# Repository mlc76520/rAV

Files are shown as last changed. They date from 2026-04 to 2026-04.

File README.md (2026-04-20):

# Raspberry Audio Visualizer

A real-time stereo audio visualizer for Raspberry Pi that drives **two SSD1309 128×64 OLED displays** over SPI. Written in a single C++ file with a hardware abstraction layer that lets the same source build on both the **Raspberry Pi 5** (via `lgpio`) and the **Raspberry Pi 3B** (via `bcm2835`).

The project combines live FFT analysis of the system audio output, a full MPD client, Bluetooth (A2DP) metadata monitoring, and a small physical control surface (rotary encoder + four buttons) into a standalone "hi-fi display" appliance.
---
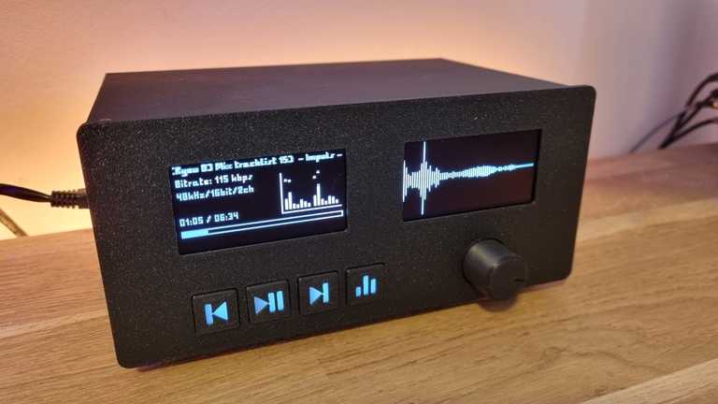
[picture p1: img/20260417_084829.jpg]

---

## Features

- **Six visualization modes**, switchable with a button or auto-cycled after 30 s of inactivity
- **Two independent OLEDs** — left and right channels rendered separately
- **Three-resolution FFT** (8192 / 2048 / 512 points) for accurate bass, mid, and treble bins
- **64-band and 7-band spectrum analyzers** with peak-hold, smoothing, and gravity decay
- **MPD integration** — now-playing info, play/pause, next/previous, volume, and a built-in album/track browser
- **Bluetooth A2DP monitoring** via BlueZ D-Bus — track metadata and auto-pause MPD on BT connect
- **FreeType text rendering** with small / regular / large sizes and UTF-8 support
- **Sleep mode** — after 10 s of silence, both displays fade out with a CRT-style shutdown animation; they wake when audio returns
- **Unified build** — one source file, two backends, selected at compile time with `-DUSE_BCM2835`

---

## Visualization Modes

| Mode | Description |
|---|---|
| **VU Meter** | Analog-style needle with logarithmic dB scale (−20 to +3 dB) |
| **Spectrum** | 7-band filled bars with peak markers and frequency labels (63 Hz → 16 kHz) |
| **Empty Spectrum** | Same 7 bands, outline-only style |
| **Waveform** | Time-domain oscilloscope trace |
| **Track Info** | Scrolling title, bitrate/format, elapsed/total time, progress bar, plus a 64-band mini-spectrum |
| **Playlist Editor** | Browse albums → tracks; play now or add to queue *(UI labels in French)* |

A short volume overlay is drawn over the current visualization whenever the rotary knob is turned.

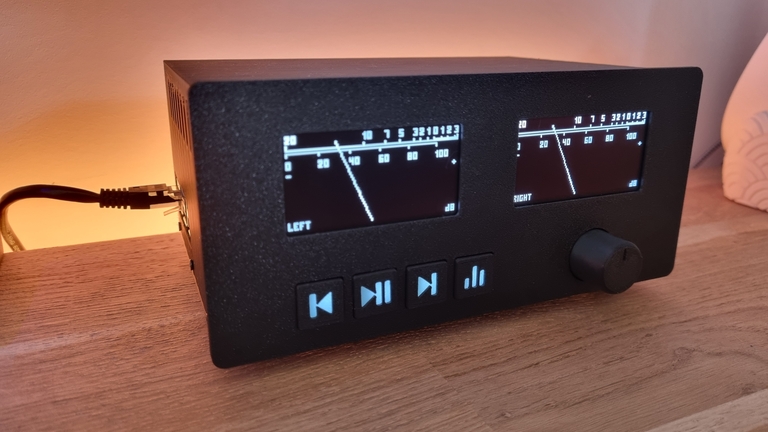
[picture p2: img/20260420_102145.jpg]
VUmeter

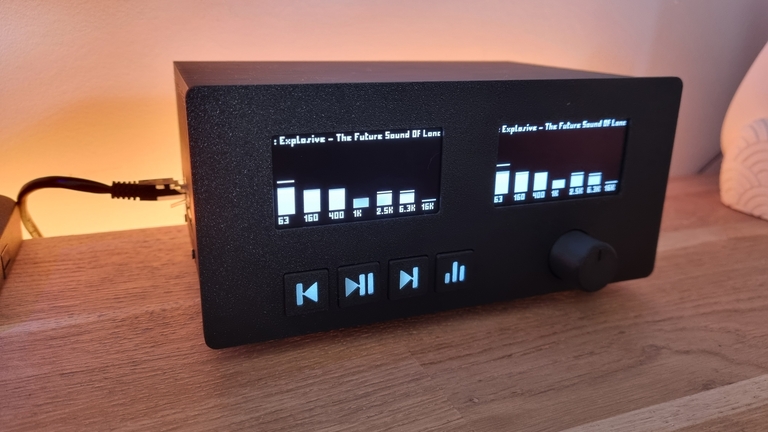
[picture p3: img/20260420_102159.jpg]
Spectrum

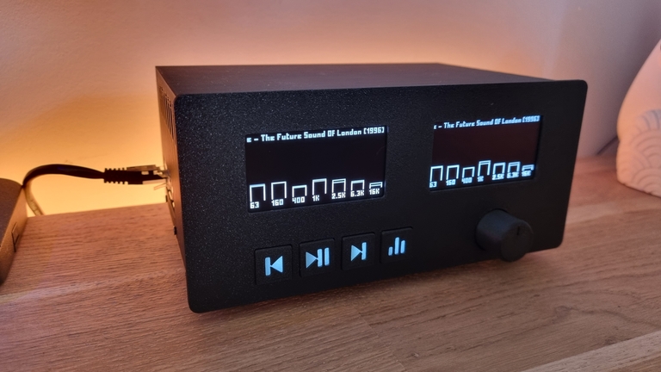
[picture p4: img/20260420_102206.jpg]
Empty spectrum

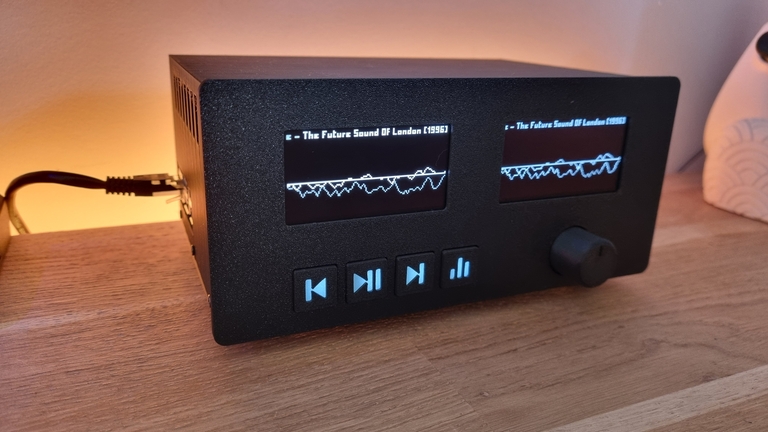
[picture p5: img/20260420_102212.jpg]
Waveform

Trackinfo
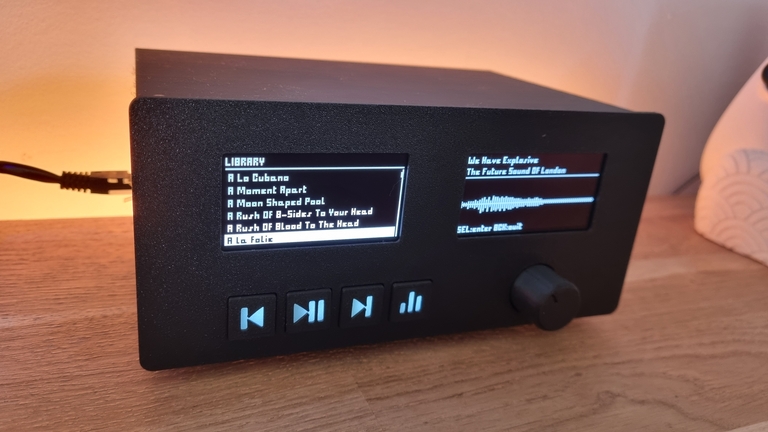
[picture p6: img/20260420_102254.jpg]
Library


---
## Parts list
- 1 Raspberry pi 3B or 5
- 1 Rotary encoder 
- 2 128x64 waveshare SPI OLED screens white
- 4 momentary pushbuttons
- 4 smd1206 LEDs 6000k
- 1 100nF capacitor
- 1 220ohms resistor
- Board for screens
- 2*8cm Board for pushbuttons
- Optional: Audio HAT for RPI 5

---
## 3D printed parts
- M2.5 Threaded Insert
- M2.5×8mm screws
- Feet Stickers, 18 x 10 mm Rubber Pads Self Adhesive Half Sphere

---
## wiring

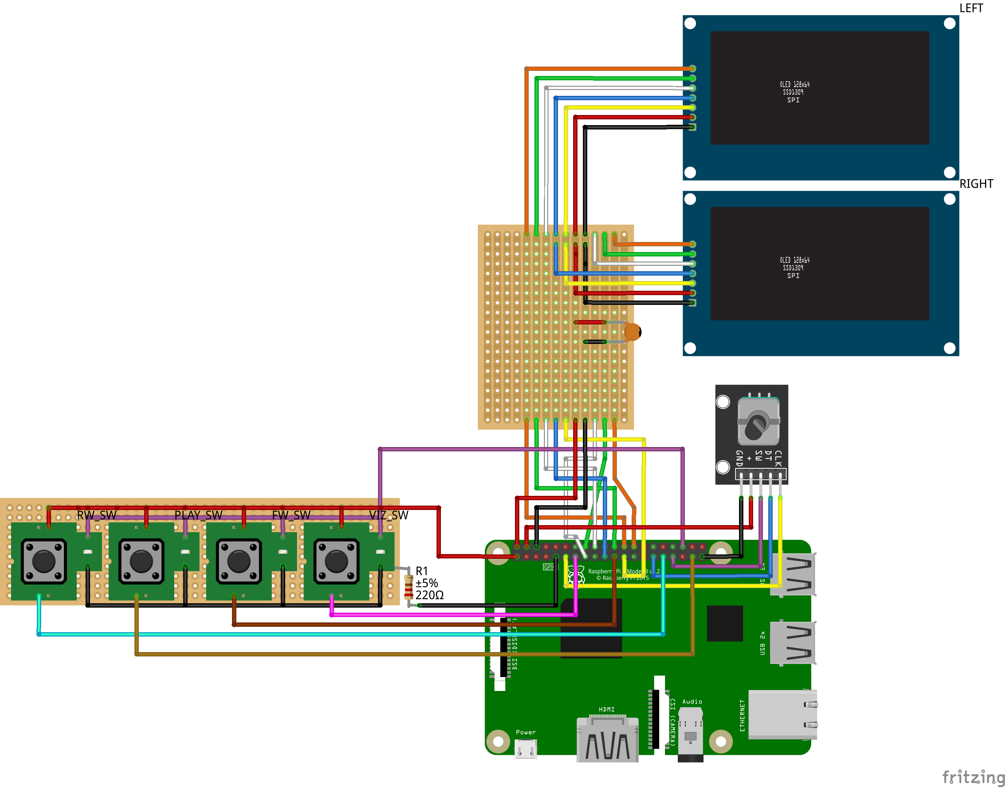
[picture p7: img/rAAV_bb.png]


---
## Hardware

### Displays
- 2× SSD1309 OLED, 128×64, SPI mode

### GPIO Pinout (BCM numbering)

| Function | Pin | Function | Pin |
|---|---|---|---|
| Left display CS | 8 | Right display CS | 7 |
| Left display DC | 25 | Right display DC | 23 |
| Left display RST | 24 | Right display RST | 22 |
| Rotary CLK | 17 | Rotary DT | 5 |
| Rotary switch | 13 | Viz switch | 27 |
| Play/Pause button | 26 | Prev button | 6 |
| Next button | 9 | Power LED | 16 |

SPI runs at 10 MHz on the RPi 5 and ~6.25 MHz on the RPi 3B (stable without an extra decoupling cap).

### Controls

| Input | Action |
|---|---|
| Rotary knob | Volume ±2 (normal mode) / scroll list (editor mode) |
| Rotary push | Open Playlist Editor / confirm selection |
| Viz button | Cycle to next visualization / exit editor |
| Play button | Play / pause (MPD) |
| Next / Prev buttons | Skip track (MPD) |

---

## Dependencies

Common to both targets:

```
g++  pkg-config
libdbus-1-dev         # Bluetooth via BlueZ D-Bus
libasound2-dev        # ALSA capture
libfftw3-dev          # FFT (single-precision)
libfreetype-dev       # Text rendering
libmpdclient-dev      # MPD client
```

Plus **one** of:

- `liblgpio-dev` (Raspberry Pi 5)
- [`bcm2835`](https://www.airspayce.com/mikem/bcm2835/) library (Raspberry Pi 3B — install from source)

---

## Building

### Raspberry Pi 5 (lgpio backend)

```bash
sudo apt install g++ pkg-config libdbus-1-dev libasound2-dev \
                 libfftw3-dev libfreetype-dev libmpdclient-dev liblgpio-dev

g++ -o visualizer rav_unified.cpp \
    -O3 -march=native -std=c++23 \
    -I/usr/include/freetype2 \
    $(pkg-config --cflags --libs dbus-1) \
    -fstack-protector-strong -D_FORTIFY_SOURCE=2 -fPIE -pie -Wl,-z,relro,-z,now \
    -llgpio -lpthread -lasound -lfftw3f -lm -lfreetype -lmpdclient
```

### Raspberry Pi 3B (bcm2835 backend)

```bash
sudo apt install g++ pkg-config libdbus-1-dev libasound2-dev \
                 libfftw3-dev libfreetype-dev libmpdclient-dev
# Install bcm2835 from https://www.airspayce.com/mikem/bcm2835/

g++ -o visualizer rav_unified.cpp \
    -O3 -march=native -std=c++17 -DUSE_BCM2835 \
    -I/usr/include/freetype2 \
    $(pkg-config --cflags --libs dbus-1) \
    -fstack-protector-strong -D_FORTIFY_SOURCE=2 -fPIE -pie -Wl,-z,relro,-z,now \
    -lbcm2835 -lpthread -lasound -lfftw3f -lm -lfreetype -lmpdclient
```

The only difference is the `-DUSE_BCM2835` flag and the GPIO library. Everything else — the visualizations, MPD client, Bluetooth monitor, audio pipeline — is shared.

---

## Runtime Setup

### 1. ALSA loopback for audio capture

The visualizer opens an ALSA capture device named `rav` (falling back to `hw:Loopback,1`). The easiest way to feed it system audio is the kernel `snd-aloop` module:

```bash
sudo modprobe snd-aloop
# and make permanent in /etc/modules
```

Route your player (MPD, BT, etc.) to the loopback **playback** side; the visualizer reads the matching **capture** side. A named PCM called `rav` in `~/.asoundrc` or `/etc/asound.conf` pointing at the loopback capture device is the cleanest setup.

Audio is read as 44.1 kHz, 16-bit, stereo, 2048-frame periods.

### 2. MPD

MPD is expected on `localhost:6600` (hard-coded default in `MPDClient`). It connects in the background and will keep retrying until MPD is available, so boot order doesn't matter.

### 3. Fonts

At startup the program tries, in order:

1. `trixel-square.ttf` in the working directory
2. `/usr/share/fonts/truetype/dejavu/DejaVuSans.ttf`

Drop a `trixel-square.ttf` next to the binary for the intended pixel-font look, or rely on DejaVu as a fallback.

### 4. Bluetooth (optional)

If BlueZ is running, the visualizer subscribes to `PropertiesChanged` on `org.bluez.MediaPlayer1` / `MediaTransport1`. When a phone connects and starts A2DP playback, MPD is auto-paused and the displays switch to showing Bluetooth track metadata.

---

## Architecture

```
┌────────────────────────────────────────────────────────────┐
│                      VisualizerApp                         │
│                                                            │
│   ┌──────────────┐  ┌───────────────┐  ┌──────────────┐    │
│   │ AudioProcessor│  │   MPDClient   │  │  Bluetooth   │    │
│   │  (ALSA + 3×  │  │   (idle loop  │  │   Monitor    │    │
│   │   FFTW plans)│  │   thread)     │  │  (D-Bus thr) │    │
│   └──────┬───────┘  └──────┬────────┘  └──────┬───────┘    │
│          │                 │                  │            │
│          ▼                 ▼                  ▼            │
│   ┌────────────────────────────────────────────────────┐   │
│   │               Visualization (×6)                   │   │
│   │      VU / Spectrum / Waveform / Track / Editor     │   │
│   └─────────────────────┬──────────────────────────────┘   │
│                         ▼                                  │
│   ┌─────────────────┐       ┌─────────────────┐            │
│   │  Display LEFT   │       │  Display RIGHT  │            │
│   └────────┬────────┘       └────────┬────────┘            │
│            ▼                         ▼                     │
│   ┌────────────────────────────────────────────┐           │
│   │       HardwareLayer (abstract)             │           │
│   │   ├── LGpioBackend   (RPi 5, interrupts)   │           │
│   │   └── BCM2835Backend (RPi 3B, polling)     │           │
│   └────────────────────────────────────────────┘           │
└────────────────────────────────────────────────────────────┘
```

### Threads

| Thread | Role |
|---|---|
| Main | Rendering loop (~60 FPS), input polling, sleep/wake state machine |
| Audio | Blocking ALSA reads → circular buffer |
| MPD | `mpd_send_idle` loop + periodic bitrate refresh |
| Bluetooth | D-Bus message dispatch |
| Rotary poll (RPi 3B only) | 1 kHz GPIO polling (RPi 5 uses `lgpio` alerts/IRQ instead) |
| Editor load | Async album/track fetch from MPD, so the UI never blocks |

### Audio pipeline

1. ALSA captures 2048-frame stereo periods at 44.1 kHz.
2. Samples land in a circular buffer sized `2 × 8192`.
3. Three FFTW plans run in parallel on Hann-windowed slices:
   - **Bass** (8192 pts) for the low bands — fine frequency resolution
   - **Mid** (2048 pts) for mid-range bands
   - **Treble** (512 pts) for high bands — fast response
4. Each output bin is energy-summed into a freq band, multiplied by a per-band correction curve, then smoothed with an integral filter + gravity decay before being clamped to 0–255 for display.

This tri-resolution approach gives low-latency treble without sacrificing bass precision — a trick borrowed from projects like `cava`.

### Sleep mode

A silence-detector watches peak amplitude. After 10 s below threshold the app runs a CRT-collapse animation on both screens (vertical pinch → horizontal line → blank), puts the SSD1309s into sleep command `0xAE`, and turns off the power LED. Any audio above threshold (or any button press) reverses the animation and resumes rendering.

---

## Project Layout

A single translation unit, roughly organized as:

```
rav_unified.cpp
├── Config             — pin map, SPI, screen constants
├── HardwareLayer      — abstract class + LGpio / BCM2835 backends
├── MPDClient          — connection, metadata, control, library queries
├── BluetoothMonitor   — BlueZ D-Bus listener
├── FontManager        — FreeType wrapper, UTF-8 decoder
├── Display            — SSD1309 driver + framebuffer primitives
├── AudioProcessor     — ALSA capture + 3× FFTW analysis
├── TextScroller       — ping-pong marquee
├── Visualization      — base class
│   ├── VUMeterViz
│   ├── SpectrumViz / EmptySpectrumViz
│   ├── WaveformViz
│   ├── TrackInfoViz
│   └── PlaylistEditorViz
├── RotaryEncoder      — interrupt-driven (lgpio) or polled (bcm2835)
└── VisualizerApp      — wiring, main loop, CRT animation, sleep logic
```

---

## Running

```bash
# Usually needs root for GPIO/SPI access (or appropriate udev rules / groups)
sudo ./visualizer
```

`SIGINT` / `SIGTERM` triggers a clean shutdown: threads are joined, displays cleared and put to sleep, GPIO released.

---

## Notes & Tweaks

- **Frame rate** is capped at ~60 FPS (16 ms frame time) in `VisualizerApp::run()`.
- **Auto-cycle interval** is 30 s idle then cycles every `CYCLE_INTERVAL` frames (`= 36000`, ~10 min at 60 FPS).
- **Sensitivity / noise reduction** can be adjusted via `AudioProcessor::setSensitivity(10–300)` and `setNoiseReduction(0–100)`.
- **MPD host/port** are hard-coded in `MPDClient`'s constructor (`localhost:6600`); change there if needed.
- **GPIO chip number** defaults to `4` (RPi 5) with a fallback to `0` (older Pis running lgpio).

## Inspirations
- CAVA: https://github.com/karlstav/cava
- VU_meter: https://github.com/adamples/VU_meter/
- Digital VU Meter with Analog Physics: https://hackaday.io/project/181004-digital-vu-meter-with-analog-physics

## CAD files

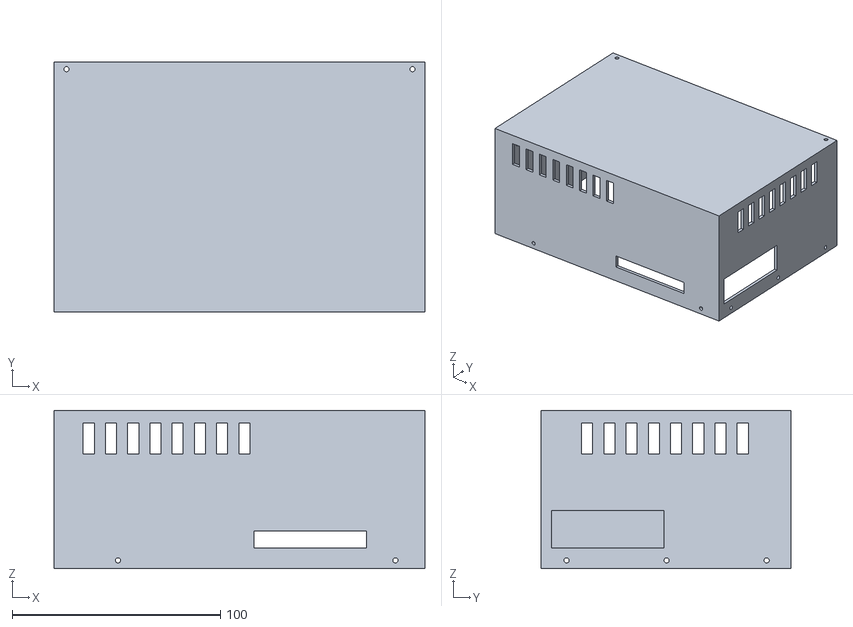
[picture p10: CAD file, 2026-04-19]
3D files/rav_frame_top_common_RPI_noHat.stl
178.0 x 120.0 x 76.0

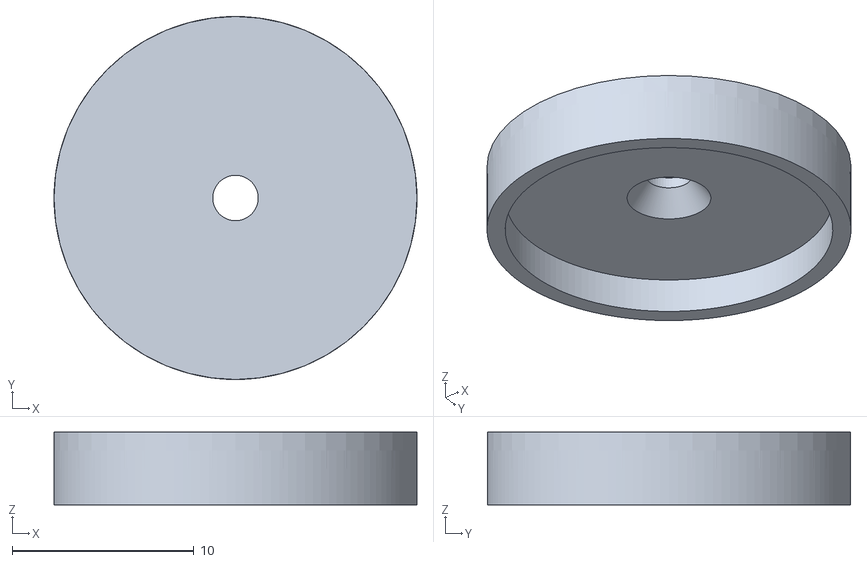
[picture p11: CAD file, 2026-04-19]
3D files/rav_frame_feet.stl
20.0 x 20.0 x 4.00

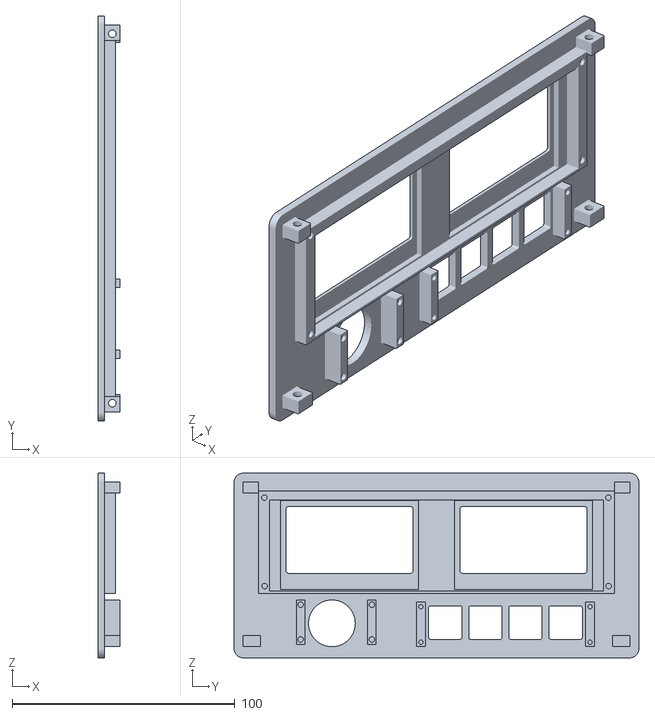
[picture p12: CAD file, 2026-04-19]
3D files/rav_frame_faceplate.stl
10.0 x 182.0 x 83.0

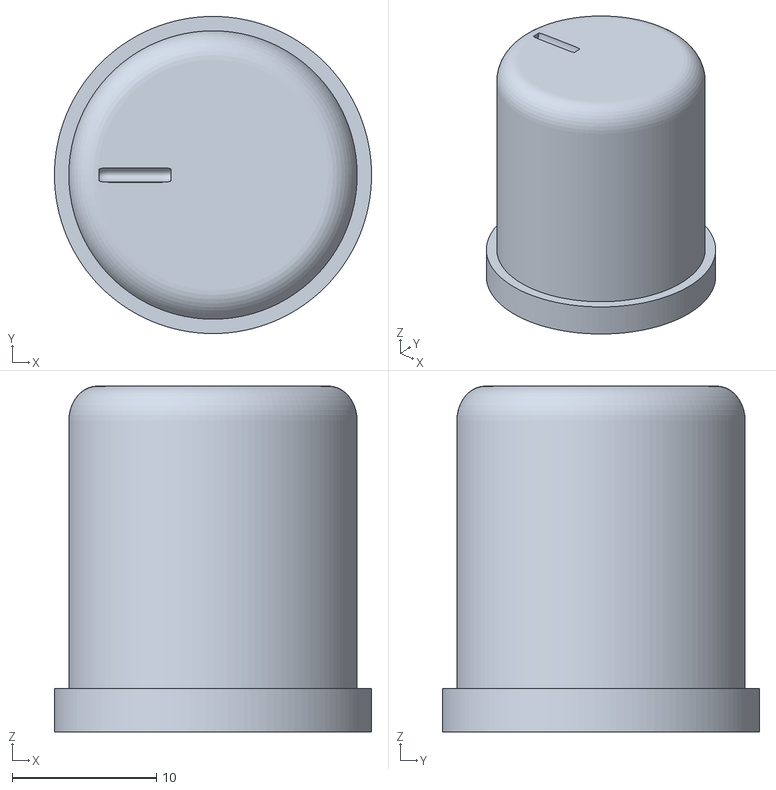
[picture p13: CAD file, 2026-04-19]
3D files/rav_rotary.stl
22.0 x 22.0 x 24.0

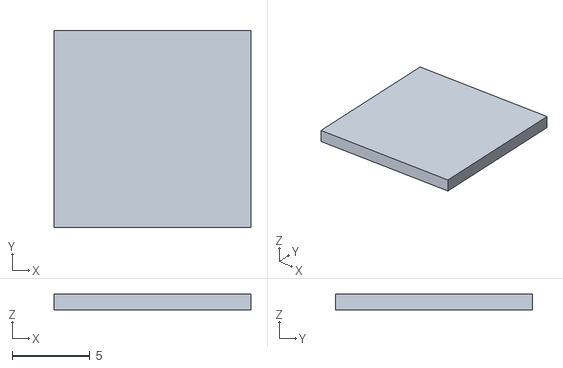
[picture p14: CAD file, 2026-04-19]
3D files/rav_buttonDiffuser.stl
12.6 x 12.6 x 1

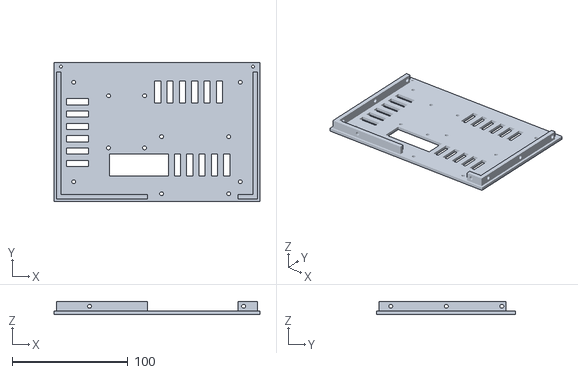
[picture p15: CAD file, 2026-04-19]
3D files/rav_frame_bottom_common.stl
178.0 x 120.0 x 11.0

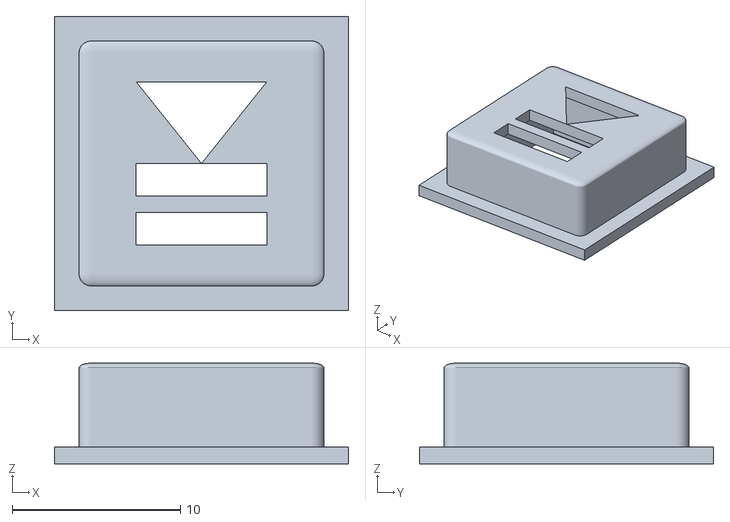
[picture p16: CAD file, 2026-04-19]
3D files/rav_PP_button.stl
17.5 x 17.5 x 6.00

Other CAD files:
3D files/rav_frame_top_RPI_Hat.stl
3D files/rav_VIZ_button.stl
3D files/rav_FF_FW_button.stl

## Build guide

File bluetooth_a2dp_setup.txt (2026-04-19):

================================================================================
BLUETOOTH A2DP SETUP FOR RASPBERRY PI AUDIO VISUALIZER
================================================================================

This guide sets up a Raspberry Pi as a Bluetooth A2DP audio receiver (sink)
with automatic pairing and no PIN authentication.

================================================================================
STEP 1: INSTALL REQUIRED PACKAGES
================================================================================

sudo apt update
sudo apt install bluez-tools bluez-alsa-utils

================================================================================
STEP 2: CONFIGURE BLUETOOTH ADAPTER
================================================================================

Edit /etc/bluetooth/main.conf

Find and uncomment/modify these lines in the [General] section:

Class = 0x240414
DiscoverableTimeout = 0
AlwaysPairable = true
PairableTimeout = 0

In the [Policy] section, ensure:

AutoEnable=true

Note: The "Name" setting is overridden by the hostname plugin.
To change the Bluetooth name, edit /etc/machine-info and add:
PRETTY_HOSTNAME=YourDeviceName

================================================================================
STEP 3: CREATE PIN CONFIG FILE
================================================================================

sudo nano /etc/bluetooth/pin.conf

Content:
---
* 0000
---

Set permissions:

sudo chown root:root /etc/bluetooth/pin.conf
sudo chmod 600 /etc/bluetooth/pin.conf

================================================================================
STEP 4: CREATE BT-AGENT SERVICE
================================================================================

sudo nano /etc/systemd/system/bt-agent.service

Content:
---
[Unit]
Description=Bluetooth Auth Agent
After=bluetooth.service
PartOf=bluetooth.service

[Service]
Type=simple
ExecStart=/usr/bin/bt-agent -c NoInputNoOutput -p /etc/bluetooth/pin.conf
Restart=on-failure
RestartSec=5

[Install]
WantedBy=bluetooth.target
---

================================================================================
STEP 5: CREATE BLUEALSA SERVICE
================================================================================

sudo nano /etc/systemd/system/bluealsa.service

Content:
---
[Unit]
Description=BlueALSA daemon
After=bluetooth.service
Requires=bluetooth.service

[Service]
Type=simple
ExecStart=/usr/bin/bluealsa -p a2dp-sink
Restart=on-failure
RestartSec=5

[Install]
WantedBy=multi-user.target
---

================================================================================
STEP 6: CREATE BT-DISCOVERABLE SERVICE
================================================================================

The main.conf DiscoverableTimeout=0 means "stay discoverable forever once enabled"
but doesn't auto-enable discoverable mode. This service does that at boot.

sudo nano /etc/systemd/system/bt-discoverable.service

Content:
---
[Unit]
Description=Make Bluetooth Discoverable
After=bluetooth.service bt-agent.service
Requires=bluetooth.service

[Service]
Type=oneshot
ExecStart=/usr/bin/bluetoothctl discoverable on
RemainAfterExit=yes

[Install]
WantedBy=multi-user.target
---

================================================================================
STEP 7: ENABLE AND START SERVICES
================================================================================

sudo systemctl daemon-reload
sudo systemctl enable bluetooth bt-agent bluealsa bt-discoverable
sudo systemctl start bluetooth bt-agent bluealsa bt-discoverable

================================================================================
STEP 8: VERIFY SETUP
================================================================================

Check services are running:

sudo systemctl status bt-agent
sudo systemctl status bluealsa
sudo systemctl status bt-discoverable

Check Bluetooth adapter status:

bluetoothctl show

Should show:
- Powered: yes
- Discoverable: yes
- Pairable: yes
- Class: 0x00040414 (audio device)

================================================================================
STEP 9: TEST CONNECTION
================================================================================

1. From your phone, search for Bluetooth devices
2. You should see your Pi's hostname (e.g., "BureauRPI")
3. Pair and connect - no PIN should be required
4. Play audio from your phone

Verify audio stream is received:

bluealsa-aplay -L

Should show something like:
bluealsa:SRV=org.bluealsa,DEV=XX:XX:XX:XX:XX:XX,PROFILE=a2dp
    Device Name, phone, capture
    A2DP (SBC): S16_LE 2 channels 44100 Hz

================================================================================
AUDIO ROUTING TO LOOPBACK (FOR VISUALIZER)
================================================================================

If using ALSA loopback for visualization, the audio is automatically
available through the loopback device when bluealsa-aplay routes to it.

To manually route Bluetooth audio to loopback:

bluealsa-aplay -d hw:Loopback,0 &

The visualizer can then capture from hw:Loopback,1

================================================================================
TROUBLESHOOTING
================================================================================

Check logs:
journalctl -u bt-agent -f
journalctl -u bluealsa -f
journalctl -u bluetooth -f

Manual Bluetooth control:
bluetoothctl
> power on
> discoverable on
> pairable on
> show

Reset Bluetooth:
sudo systemctl restart bluetooth bt-agent bluealsa

Unblock BT:
rfkill list
sudo rfkill unblock bluetooth
bluetoothctl power on

If discoverable doesn't persist after reboot:
sudo systemctl status bt-discoverable
sudo systemctl restart bt-discoverable

================================================================================
SUMMARY OF FILES CREATED/MODIFIED
================================================================================

Modified:
- /etc/bluetooth/main.conf

Created:
- /etc/bluetooth/pin.conf
- /etc/systemd/system/bt-agent.service
- /etc/systemd/system/bluealsa.service
- /etc/systemd/system/bt-discoverable.service

================================================================================

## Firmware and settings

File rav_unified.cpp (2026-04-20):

/*
Dual SSD1309 OLED Audio Visualizer for Raspberry Pi 3B / 5
Unified C++ implementation with hardware abstraction layer

=== RPi 5 (lgpio) ===
sudo apt install g++ pkg-config libdbus-1-dev libasound2-dev libfftw3-dev libfreetype-dev libmpdclient-dev liblgpio-dev

g++ -o visualizer visualizer.cpp \
    -O3 -march=native -std=c++23 \
    -I/usr/include/freetype2 \
    $(pkg-config --cflags --libs dbus-1) \
    -fstack-protector-strong -D_FORTIFY_SOURCE=2 -fPIE -pie -Wl,-z,relro,-z,now \
    -llgpio -lpthread -lasound -lfftw3f -lm -lfreetype -lmpdclient

=== RPi 3B (bcm2835) ===
sudo apt install g++ pkg-config libdbus-1-dev libasound2-dev libfftw3-dev libfreetype-dev libmpdclient-dev
# Install bcm2835 library from https://www.airspayce.com/mikem/bcm2835/

g++ -o visualizer visualizer.cpp \
    -O3 -march=native -std=c++17 -DUSE_BCM2835 \
    -I/usr/include/freetype2 \
    $(pkg-config --cflags --libs dbus-1) \
    -fstack-protector-strong -D_FORTIFY_SOURCE=2 -fPIE -pie -Wl,-z,relro,-z,now \
    -lbcm2835 -lpthread -lasound -lfftw3f -lm -lfreetype -lmpdclient
*/

#ifdef USE_BCM2835
#include <bcm2835.h>
#else
#include <lgpio.h>
#endif

#include <alsa/asoundlib.h>
#include <fftw3.h>
#include <cmath>
#include <cstring>
#include <cstdio>
#include <algorithm>
#include <thread>
#include <atomic>
#include <chrono>
#include <array>
#include <mutex>
#include <signal.h>
#include <ft2build.h>
#include <mpd/client.h>
#include <string>
#include <sstream>
#include <iomanip>
#include <vector>
#include <memory>
#include <dbus/dbus.h>
#include <functional>
#include <unistd.h>
#include FT_FREETYPE_H

// --- Configuration Constants ---
namespace Config {
    constexpr int SCREEN_WIDTH = 128;
    constexpr int SCREEN_HEIGHT = 64;
    constexpr int SPI_CHUNK_SIZE = 1024;
    constexpr uint8_t LEFT_CS = 8;
    constexpr uint8_t LEFT_DC = 25;
    constexpr uint8_t LEFT_RST = 24;
    constexpr uint8_t RIGHT_CS = 7;
    constexpr uint8_t RIGHT_DC = 23;
    constexpr uint8_t RIGHT_RST = 22;
    constexpr uint8_t VIZ_SW = 27;
    constexpr uint8_t RW_SW = 6;
    constexpr uint8_t FW_SW = 9;
    constexpr uint8_t PLAY_SW = 26;
    constexpr uint8_t POWER_LED = 16;
    constexpr uint8_t ROT_CLK = 17;
    constexpr uint8_t ROT_DT = 5;
    constexpr uint8_t ROT_SW = 13;
    constexpr int GPIO_CHIP = 4;
    constexpr int SPI_DEVICE = 0;
    constexpr int SPI_CHANNEL = 0;
    constexpr int SPI_SPEED = 10000000;
}

// ============================================================
// Hardware Abstraction Layer
// ============================================================

class HardwareLayer {
public:
    virtual ~HardwareLayer() = default;
    virtual bool init() = 0;
    virtual void cleanup() = 0;

    // GPIO
    virtual int claimOutput(int pin, int initialValue = 0) = 0;
    virtual int claimInput(int pin) = 0;
    virtual int claimInputPullUp(int pin) = 0;
    virtual void digitalWrite(int pin, int value) = 0;
    virtual int digitalRead(int pin) = 0;

    // SPI
    virtual void spiTransfer(int cs_pin, uint8_t data) = 0;
    virtual void spiWrite(int cs_pin, const char* buf, int len) = 0;

    // Timing
    virtual void delay(int ms) = 0;
    virtual void delayMicroseconds(int us) = 0;

    // Rotary encoder support (interrupt-based on lgpio, polling on bcm2835)
    virtual bool supportsAlerts() const = 0;

    // lgpio-specific alert functions (no-op on bcm2835)
    virtual int gpioHandle() const = 0;
    virtual int claimAlert(int pin, int flags, int edge) { return -1; }
    virtual int setDebounce(int pin, int us) { return -1; }
    virtual int setAlertsFunc(int pin, void* func, void* user) { return -1; }
    virtual int clearAlertsFunc(int pin) { return -1; }
};

// --- lgpio backend (RPi5) ---
#ifndef USE_BCM2835

class LGpioBackend : public HardwareLayer {
    int gpio_handle_ = -1;
    int spi_cs0_ = -1;
    int spi_cs1_ = -1;

public:
    bool init() override {
        gpio_handle_ = lgGpiochipOpen(Config::GPIO_CHIP);
        if (gpio_handle_ < 0) {
            gpio_handle_ = lgGpiochipOpen(0);
            if (gpio_handle_ < 0) {
                printf("Failed to open GPIO chip: %s\n", lguErrorText(gpio_handle_));
                return false;
            }
            printf("Using gpiochip0 (fallback)\n");
        } else {
            printf("Using gpiochip4 (RPi5)\n");
        }

        spi_cs0_ = lgSpiOpen(Config::SPI_DEVICE, 0, Config::SPI_SPEED, 0);
        if (spi_cs0_ < 0) {
            printf("Failed to open SPI CS0: %s\n", lguErrorText(spi_cs0_));
            lgGpiochipClose(gpio_handle_); gpio_handle_ = -1;
            return false;
        }

        spi_cs1_ = lgSpiOpen(Config::SPI_DEVICE, 1, Config::SPI_SPEED, 0);
        if (spi_cs1_ < 0) {
            printf("Failed to open SPI CS1: %s\n", lguErrorText(spi_cs1_));
            lgSpiClose(spi_cs0_); lgGpiochipClose(gpio_handle_);
            gpio_handle_ = -1; spi_cs0_ = -1;
            return false;
        }

        printf("SPI initialized: CS0 and CS1 at %d Hz\n", Config::SPI_SPEED);
        return true;
    }

    void cleanup() override {
        if (spi_cs0_ >= 0) { lgSpiClose(spi_cs0_); spi_cs0_ = -1; }
        if (spi_cs1_ >= 0) { lgSpiClose(spi_cs1_); spi_cs1_ = -1; }
        if (gpio_handle_ >= 0) { lgGpiochipClose(gpio_handle_); gpio_handle_ = -1; }
    }

    int claimOutput(int pin, int initialValue = 0) override {
        return lgGpioClaimOutput(gpio_handle_, 0, pin, initialValue);
    }
    int claimInput(int pin) override {
        return lgGpioClaimInput(gpio_handle_, 0, pin);
    }
    int claimInputPullUp(int pin) override {
        return lgGpioClaimInput(gpio_handle_, LG_SET_PULL_UP, pin);
    }
    void digitalWrite(int pin, int value) override {
        lgGpioWrite(gpio_handle_, pin, value);
    }
    int digitalRead(int pin) override {
        return lgGpioRead(gpio_handle_, pin);
    }

    void spiTransfer(int cs_pin, uint8_t data) override {
        char tx = data, rx = 0;
        int h = (cs_pin == Config::LEFT_CS) ? spi_cs0_ : spi_cs1_;
        lgSpiXfer(h, &tx, &rx, 1);
    }
    void spiWrite(int cs_pin, const char* buf, int len) override {
        int h = (cs_pin == Config::LEFT_CS) ? spi_cs0_ : spi_cs1_;
        lgSpiWrite(h, buf, len);
    }

    void delay(int ms) override { lguSleep(ms / 1000.0); }
    void delayMicroseconds(int us) override { lguSleep(us / 1000000.0); }

    bool supportsAlerts() const override { return true; }
    int gpioHandle() const override { return gpio_handle_; }

    int claimAlert(int pin, int flags, int edge) override {
        return lgGpioClaimAlert(gpio_handle_, flags, edge, pin, -1);
    }
    int setDebounce(int pin, int us) override {
        return lgGpioSetDebounce(gpio_handle_, pin, us);
    }
    int setAlertsFunc(int pin, void* func, void* user) override {
        return lgGpioSetAlertsFunc(gpio_handle_, pin, (lgGpioAlertsFunc_t)func, user);
    }
    int clearAlertsFunc(int pin) override {
        return lgGpioSetAlertsFunc(gpio_handle_, pin, nullptr, nullptr);
    }
};

#else // USE_BCM2835

// --- bcm2835 backend (RPi3B) ---
class BCM2835Backend : public HardwareLayer {
public:
    bool init() override {
        if (!bcm2835_init()) {
            printf("bcm2835_init failed\n");
            return false;
        }
        if (!bcm2835_spi_begin()) {
            printf("bcm2835_spi_begin failed\n");
            bcm2835_close();
            return false;
        }
        bcm2835_spi_setBitOrder(BCM2835_SPI_BIT_ORDER_MSBFIRST);
        bcm2835_spi_setDataMode(BCM2835_SPI_MODE0);
        bcm2835_spi_setClockDivider(40); // ~6.25MHz (250MHz/40) stable without capacitor

        printf("bcm2835 SPI initialized\n");
        return true;
    }

    void cleanup() override {
        bcm2835_spi_end();
        bcm2835_close();
    }

    int claimOutput(int pin, int initialValue = 0) override {
        bcm2835_gpio_fsel(pin, BCM2835_GPIO_FSEL_OUTP);
        bcm2835_gpio_write(pin, initialValue);
        return 0;
    }
    int claimInput(int pin) override {
        bcm2835_gpio_fsel(pin, BCM2835_GPIO_FSEL_INPT);
        return 0;
    }
    int claimInputPullUp(int pin) override {
        bcm2835_gpio_fsel(pin, BCM2835_GPIO_FSEL_INPT);
        bcm2835_gpio_set_pud(pin, BCM2835_GPIO_PUD_UP);
        return 0;
    }
    void digitalWrite(int pin, int value) override {
        bcm2835_gpio_write(pin, value);
    }
    int digitalRead(int pin) override {
        return bcm2835_gpio_lev(pin);
    }

    void spiTransfer(int cs_pin, uint8_t data) override {
        bcm2835_gpio_write(cs_pin, 0);
        bcm2835_spi_transfer(data);
        bcm2835_gpio_write(cs_pin, 1);
    }
    void spiWrite(int cs_pin, const char* buf, int len) override {
        bcm2835_gpio_write(cs_pin, 0);
        bcm2835_spi_transfern((char*)buf, len);
        bcm2835_gpio_write(cs_pin, 1);
    }

    void delay(int ms) override { 
        std::this_thread::sleep_for(std::chrono::milliseconds(ms));
    }
    void delayMicroseconds(int us) override { 
        std::this_thread::sleep_for(std::chrono::microseconds(us));
    }

    bool supportsAlerts() const override { return false; }
    int gpioHandle() const override { return -1; }
};

#endif // USE_BCM2835

// Global hardware pointer
static std::unique_ptr<HardwareLayer> hw;

// Auto-detect and create the right backend
std::unique_ptr<HardwareLayer> createHardware() {
#ifdef USE_BCM2835
    return std::make_unique<BCM2835Backend>();
#else
    return std::make_unique<LGpioBackend>();
#endif
}

// Forward declarations
class Display;
class AudioProcessor;
struct ControlState;

// --- MPD Client ---
class MPDClient {
    private:
        struct mpd_connection* conn;
        std::thread mpd_thread;
        std::atomic<bool> thread_running;
        std::mutex data_mutex;

        std::string formatted_text;
        std::string host;
        int port;

        std::string track_number;
        std::string title;
        std::string artist;
        std::string album;
        std::string date;
        std::string bitrate_str;
        std::string format_str;
        unsigned int elapsed_time;
        unsigned int total_time;
        bool is_playing;

        std::chrono::steady_clock::time_point last_status_update;
        std::chrono::steady_clock::time_point last_bitrate_check;

        void updateFormattedText() {
            std::lock_guard<std::mutex> lock(data_mutex);

            if (!conn || mpd_connection_get_error(conn) != MPD_ERROR_SUCCESS) {
                formatted_text = "Waiting for MPD...";
                track_number = ""; title = "No song playing"; artist = ""; album = "";
                date = ""; bitrate_str = ""; format_str = "";
                elapsed_time = 0; total_time = 0; is_playing = false;
                return;
            }

            struct mpd_song* song = mpd_run_current_song(conn);
            if (!song) {
                formatted_text = "No song playing";
                track_number = ""; title = "No song playing"; artist = ""; album = "";
                date = ""; bitrate_str = ""; format_str = "";
                elapsed_time = 0; total_time = 0; is_playing = false;
                mpd_response_finish(conn);
                return;
            }

            unsigned track = mpd_song_get_pos(song) + 1;
            const char* title_tag = mpd_song_get_tag(song, MPD_TAG_TITLE, 0);
            const char* artist_tag = mpd_song_get_tag(song, MPD_TAG_ARTIST, 0);
            const char* album_tag = mpd_song_get_tag(song, MPD_TAG_ALBUM, 0);
            const char* date_tag = mpd_song_get_tag(song, MPD_TAG_DATE, 0);

            track_number = std::to_string(track);
            title = title_tag ? title_tag : "Unknown Title";
            artist = artist_tag ? artist_tag : "Unknown Artist";
            album = album_tag ? album_tag : "Unknown Album";
            date = (date_tag && strlen(date_tag) >= 4) ? std::string(date_tag).substr(0, 4) : "";

            std::stringstream ss;
            ss << std::setfill('0') << std::setw(2) << track << ". ";
            ss << (title_tag ? title_tag : "Unknown Title");
            if (artist_tag) ss << " - " << artist_tag;
            if (date_tag && strlen(date_tag) >= 4) ss << " (" << std::string(date_tag).substr(0, 4) << ")";

            formatted_text = ss.str();
            mpd_song_free(song);
            mpd_response_finish(conn);

            struct mpd_status* status = mpd_run_status(conn);
            if (status) {
                elapsed_time = mpd_status_get_elapsed_time(status);
                total_time = mpd_status_get_total_time(status);
                is_playing = (mpd_status_get_state(status) == MPD_STATE_PLAY);

                unsigned int kbps = mpd_status_get_kbit_rate(status);
                bitrate_str = (kbps > 0) ? (std::to_string(kbps) + " kbps") : "N/A";

                const struct mpd_audio_format* format = mpd_status_get_audio_format(status);
                if (format) {
                    std::stringstream fmt;
                    fmt << (format->sample_rate / 1000) << "kHz/"
                        << (int)format->bits << "bit/"
                        << (int)format->channels << "ch";
                    format_str = fmt.str();
                } else {
                    format_str = "N/A";
                }

                mpd_status_free(status);
                last_status_update = std::chrono::steady_clock::now();
            } else {
                bitrate_str = "N/A"; format_str = "N/A"; is_playing = false;
            }
            mpd_response_finish(conn);
        }

        void refreshBitrateOnly() {
            if (!conn || mpd_connection_get_error(conn) != MPD_ERROR_SUCCESS) return;

            struct mpd_status* status = mpd_run_status(conn);
            if (status) {
                std::lock_guard<std::mutex> lock(data_mutex);
                elapsed_time = mpd_status_get_elapsed_time(status);
                is_playing = (mpd_status_get_state(status) == MPD_STATE_PLAY);
                unsigned int kbps = mpd_status_get_kbit_rate(status);
                bitrate_str = (kbps > 0) ? (std::to_string(kbps) + " kbps") : "N/A";
                mpd_status_free(status);
                last_bitrate_check = std::chrono::steady_clock::now();
            }
            mpd_response_finish(conn);
        }

        void mpdThreadFunc() {
            printf("MPD thread started\n");

            while (thread_running) {
                if (!conn) {
                    conn = mpd_connection_new(host.c_str(), port, 5000);
                    if (!conn || mpd_connection_get_error(conn) != MPD_ERROR_SUCCESS) {
                        if (conn) { mpd_connection_free(conn); conn = nullptr; }
                        for (int i = 0; i < 50; ++i) {
                            if (!thread_running) return;
                            std::this_thread::sleep_for(std::chrono::milliseconds(100));
                        }
                        continue;
                    }
                    printf("Connected to MPD at %s:%d\n", host.c_str(), port);
                    updateFormattedText();
                }

                if (!mpd_send_idle_mask(conn, MPD_IDLE_PLAYER)) {
                    printf("MPD idle failed, reconnecting...\n");
                    mpd_connection_free(conn); conn = nullptr;
                    continue;
                }

                int fd = mpd_connection_get_fd(conn);
                if (fd < 0) {
                    printf("Invalid MPD connection fd\n");
                    mpd_connection_free(conn); conn = nullptr;
                    continue;
                }

                fd_set read_fds;
                struct timeval tv;

                while (thread_running) {
                    FD_ZERO(&read_fds);
                    FD_SET(fd, &read_fds);
                    tv.tv_sec = 0; tv.tv_usec = 100000;

                    int ret = select(fd + 1, &read_fds, nullptr, nullptr, &tv);

                    if (ret < 0) {
                        printf("Select error, reconnecting...\n");
                        mpd_connection_free(conn); conn = nullptr;
                        break;
                    } else if (ret == 0) {
                        auto now = std::chrono::steady_clock::now();
                        auto diff = std::chrono::duration_cast<std::chrono::milliseconds>(
                            now - last_bitrate_check).count();

                        if (diff >= 1000) {
                            mpd_run_noidle(conn);
                            if (mpd_connection_get_error(conn) != MPD_ERROR_SUCCESS) {
                                printf("MPD connection error after noidle: %s\n",
                                    mpd_connection_get_error_message(conn));
                                mpd_connection_free(conn); conn = nullptr;
                                break;
                            }
                            refreshBitrateOnly();
                            break;
                        }
                        continue;
                    } else {
                        enum mpd_idle events = mpd_recv_idle(conn, false);
                        if (mpd_connection_get_error(conn) != MPD_ERROR_SUCCESS) {
                            printf("MPD connection error: %s\n",
                                mpd_connection_get_error_message(conn));
                            mpd_connection_free(conn); conn = nullptr;
                            break;
                        }
                        if (events & MPD_IDLE_PLAYER) updateFormattedText();
                        break;
                    }
                }
            }

            if (conn) { mpd_connection_free(conn); conn = nullptr; }
            printf("MPD thread stopped\n");
        }

        void withMPD(std::function<void(mpd_connection*)> action) {
            struct mpd_connection* ctrl = mpd_connection_new(host.c_str(), port, 1000);
            if (ctrl && mpd_connection_get_error(ctrl) == MPD_ERROR_SUCCESS)
                action(ctrl);
            if (ctrl) mpd_connection_free(ctrl);
        }

    public:
        MPDClient(const std::string& mpd_host = "localhost", int mpd_port = 6600)
            : conn(nullptr), thread_running(false), host(mpd_host), port(mpd_port) {
            formatted_text = "Waiting for MPD...";
            track_number = ""; title = "No song playing"; artist = ""; album = "";
            date = ""; bitrate_str = ""; format_str = "";
            elapsed_time = 0; total_time = 0; is_playing = false;
            last_status_update = std::chrono::steady_clock::now();
            last_bitrate_check = std::chrono::steady_clock::now();
        }

        ~MPDClient() { stop(); }

        bool start() {
            if (thread_running) return true;
            thread_running = true;
            mpd_thread = std::thread(&MPDClient::mpdThreadFunc, this);
            return true;
        }

        void stop() {
            if (!thread_running) return;
            thread_running = false;
            if (mpd_thread.joinable()) mpd_thread.join();
        }

        std::string getFormattedText() { std::lock_guard<std::mutex> lock(data_mutex); return formatted_text; }
        std::string getTrackNumber()   { std::lock_guard<std::mutex> lock(data_mutex); return track_number; }
        std::string getTitle()         { std::lock_guard<std::mutex> lock(data_mutex); return title; }
        std::string getArtist()        { std::lock_guard<std::mutex> lock(data_mutex); return artist; }
        std::string getAlbum()         { std::lock_guard<std::mutex> lock(data_mutex); return album; }
        std::string getDate()          { std::lock_guard<std::mutex> lock(data_mutex); return date; }
        std::string getBitrate()       { std::lock_guard<std::mutex> lock(data_mutex); return bitrate_str; }
        std::string getFormat()        { std::lock_guard<std::mutex> lock(data_mutex); return format_str; }
        unsigned int getElapsedTime()  { std::lock_guard<std::mutex> lock(data_mutex); return elapsed_time; }
        unsigned int getTotalTime()    { std::lock_guard<std::mutex> lock(data_mutex); return total_time; }

        std::string formatTime(unsigned int seconds) {
            char buffer[16];
            snprintf(buffer, sizeof(buffer), "%02u:%02u", seconds / 60, seconds % 60);
            return std::string(buffer);
        }

        void playPause() {
            withMPD([this](auto* c) {
                if (is_playing) mpd_run_toggle_pause(c);
                else mpd_run_play(c);
            });
        }
        void nextTrack() { withMPD([](auto* c) { mpd_run_next(c); }); }
        void prevTrack() { withMPD([](auto* c) { mpd_run_previous(c); }); }

        void updateElapsedTime() {
            std::lock_guard<std::mutex> lock(data_mutex);
            if (is_playing && total_time > 0) {
                auto now = std::chrono::steady_clock::now();
                auto diff = std::chrono::duration_cast<std::chrono::seconds>(
                    now - last_status_update).count();
                if (diff > 0) {
                    elapsed_time += diff;
                    if (elapsed_time > total_time) elapsed_time = total_time;
                    last_status_update = now;
                }
            }
        }

        struct TrackInfo {
            std::string title, artist, file, track_num;
        };
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
int main() {
    signal(SIGINT, sig_handler);
    signal(SIGTERM, sig_handler);

    try {
        VisualizerApp app;
        app.run();
    } catch (std::exception& e) {
        printf("Error: %s\n", e.what());
        if (hw) hw->cleanup();
        return 1;
    }

    printf("Clean exit.\n");
    return 0;
}

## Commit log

2026-04-19 New baseline
    [rav_FF_FW_button.stl, rav_PP_button.stl, rav_VIZ_button.stl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]
2026-04-20 Revise parts list and add 3D printed parts section
    Updated parts list with specific component details and added a new section for 3D printed parts.
2026-10-09 PipeWire capture, Debian package and code review
    Visualizer:
    - Capture the default output's monitor through PipeWire (passive, so
    the output can still suspend); ALSA loopback kept as fallback
    - Lower latency: 4096-point bass FFT, windows aligned to the newest
    samples, read-head latency derived from the delivery size
    - Transport buttons drive a connected phone over AVRCP
    - Review fixes: UTF-8 overread, MPD elapsed-time drift and lost idle
    events, Bluetooth pause/resume, data races, PCM double close
    - FFTW wisdom cached in the systemd state directory
    Packaging: packaging/build-deb.sh builds rav-audio, which installs the
    visualizer and runs MPD and Bluetooth A2DP through a PipeWire insta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
2026-10-16 Bluetooth: return to MPD when the phone disconnects
    bluez deletes the A2DP transport on disconnect without a State change,
    so the visualizer kept showing the phone's track forever. Track the
    transport path and end streaming on InterfacesRemoved or Device1
    Connected=false.
2026-10-16 Rust version: one program for the SSD1309 and SSD1322 panels
    Merges the Rust port of rav_unified.cpp (SSD1309 128x64 mono, Pi 3)
    with the Rust port of the SSD1322 240x128 greyscale variant (Pi 5).
    A display profile, chosen with RAV_DISPLAY or
    /etc/rav-audio/visualizer.conf, carries what differs: panel driver,
    geometry, pins, fonts, FFT size and band table, knob direction, volume
    overlay, visualization set and optional features. Everything else is
    shared: grey-level canvas, PipeWire capture and analysis, MPD,
    Bluetooth (with the disconnect fix), encoder, playlist editor (one
    layout per panel), Matrix transition and the main loop.
    cargo check and the offline render test (PNG of every visualiz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
2026-10-16 CLAUDE.md: merged Rust version tested on the SSD1309; SPI pin pitfall after the C++
2026-10-16 rav-audio 2.0: package the Rust visualizer
    - build-deb.sh builds rust/ (one job under 2 GB of RAM, where a
    parallel LTO link gets rustc OOM-killed) instead of the C++
    - audio-visualizer.service runs as user mpd with the gpio and spi
    groups instead of root; ProtectHome=read-only so PipeWire's socket
    in /run/user stays reachable
    - /etc/rav-audio/visualizer.conf selects the panel (ssd1309/ssd1322)
    - polkit rule: user mpd may power the box off (hold PLAY)
    - postinst: on upgrade from 1.x on a Pi 3, stop the old visualizer and
    restore the SPI pins the bcm2835 library left as inputs; warn when
    the SSD1322 font is missing
    - FW button on GPIO 4 on the SSD1309 box too: GPIO 9 is SPI0 MISO,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
2026-10-16 rav-audio 2.0.3: ship visualizer.conf, Pi 5 DAC priority, MPD on the network
    - /etc/rav-audio/visualizer.conf was never committed: "visualizer.*" in
    .gitignore hid it, so a package built from a clean clone lacked it
    - WirePlumber: the I2S DAC is platform-soc_107c000000_sound on the Pi 5,
    not platform-soc_sound; match both so it keeps the top priority
    - MPD listens on all interfaces: both boxes are driven by network clients
    Tested on the SSD1322 box (Pi 5, HifiBerry DAC+): display, buttons,
    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
2026-10-17 Editor: a menu for the queue, albums, folders and stored playlists
    Pressing the encoder now opens a LIBRARY menu instead of the album list:
    - Queue: jump to a song (the cursor starts on the current one)
    - Albums: as before
    - Folders: browse music_directory; play or queue a folder, queue a track
    - Playlists: play or queue a stored playlist, queue a track
    The editor keeps a stack of screens whose rows carry their action; VIZ goes
    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
2026-10-17 Matrix transition: wipe from the old visualization to the new one
    The rain used to replace both for 1.6 s and fade to black. Now each column
    wipes down over the old visualization's last frame and uncovers the new
    one, running live, behind its trail; every column has left the screen
    within 750 ms.
2026-10-17 CLAUDE.md: rate switching checked on the SalonRPI's S/PDIF output
2026-10-17 Present rAV as a physical front panel for MPD
    The visualizer has grown into a full player front end: knob and buttons
    drive MPD and its library, a phone over Bluetooth, and the panels show
    live visualizations. The README intro and features (grouped as Player,
    Bluetooth, Displays), the crate and the package descriptions now say so.
    The parts list mentions the SSD1322 panels.
2026-10-19 Settings menu on a long PLAY press
    Holding PLAY for 1 s now opens a SETTINGS menu instead of powering off
    after 3 s:
    - Network: host name, wired or Wi-Fi (network and signal from nmcli when
    available) and the IPv4 address of each interface
    - Bluetooth: the controller's name, On/Off and Visible switches; they
    last until the next boot (AutoEnable, bt-discoverable)
    - Restart and Power off, each behind a No/Yes confirmation
    It shares the editor's screen stack: the encoder opens the library menu,
    PLAY the settings one. The polkit rule also lets user mpd reboot.
2026-10-19 Library over NFS, read by MPD itself; library playlists in the menu
    - mpd.conf: music_directory is nfs://192.168.0.15/... (MPD's libnfs
    storage, by IPv4: the export only allows the IPv4 LAN) instead of a
    CIFS mount; playlist_directory is local, as MPD requires
    - Playlists lists the stored playlists, then the playlist files of the
    library's playlists/ folder (the shared web radios); Folders shows
    playlist files too, opened like any playlist
    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
2026-10-22 Track Info: hatched progress bar and a radio icon for streams
    A web radio has no duration, so its progress bar was missing. Now:
    - the bar keeps its frame, filled with diagonal hatching scrolling to the
    right; the time reads "mm:ss / LIVE"
    - a radio set icon fills the free space above it: 16x10 on the SSD1309,
    a native 32x20 greyscale drawing on the SSD1322
    The progress bar, time text and icon are shared in ui.rs; the render test
    adds a "Track Info stream" frame.
2026-10-22 Track Info: an icon for each source
    Next to the radio set of streams, a library track shows a disc (a CD on
    the SSD1309, a vinyl with faint grooves on the SSD1322) and a phone over
    Bluetooth the Bluetooth rune. ui::radio_icon becomes ui::source_icon;
    the render test adds a Bluetooth frame.
